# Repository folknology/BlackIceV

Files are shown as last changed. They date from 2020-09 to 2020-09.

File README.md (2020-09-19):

# BlackIce V
BlackIce V is the 6th generation of a long line of OpenSource Hardware FPGA boards designed by the myStorm community since 2016. Unlike it's predecessors based on the Ice40 HX range, the 'V' is based on the Lattice Ice40 UltraPlus up5K and offers great new features like DSP blocks and generous internal SRAM.

Current status is hardware design, you can see the developments we are making on my regular streams :
*  [Live Stream, 8pm BST](https://www.twitch.tv/folknology)
* [Historic streams](https://www.youtube.com/watch?v=79OoLG_Dxk0&list=PLXS9jyX9czzodpJNL-szsMfl0rOrZk4B7)
Or at the join us at the [myStorm community forum](https://forum.mystorm.uk)

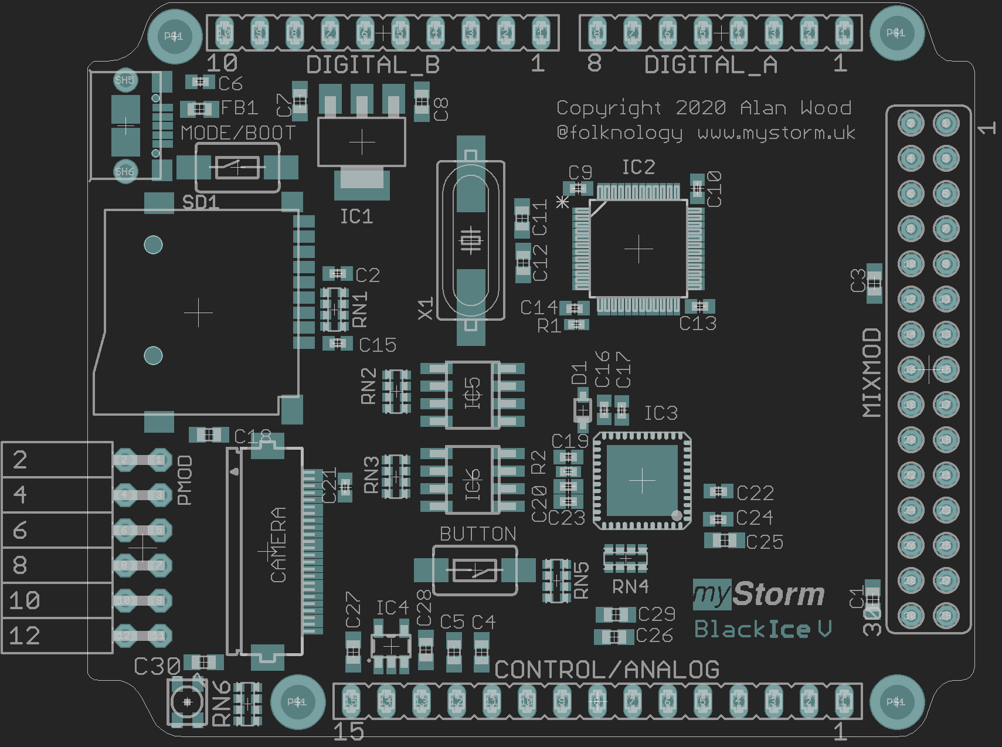
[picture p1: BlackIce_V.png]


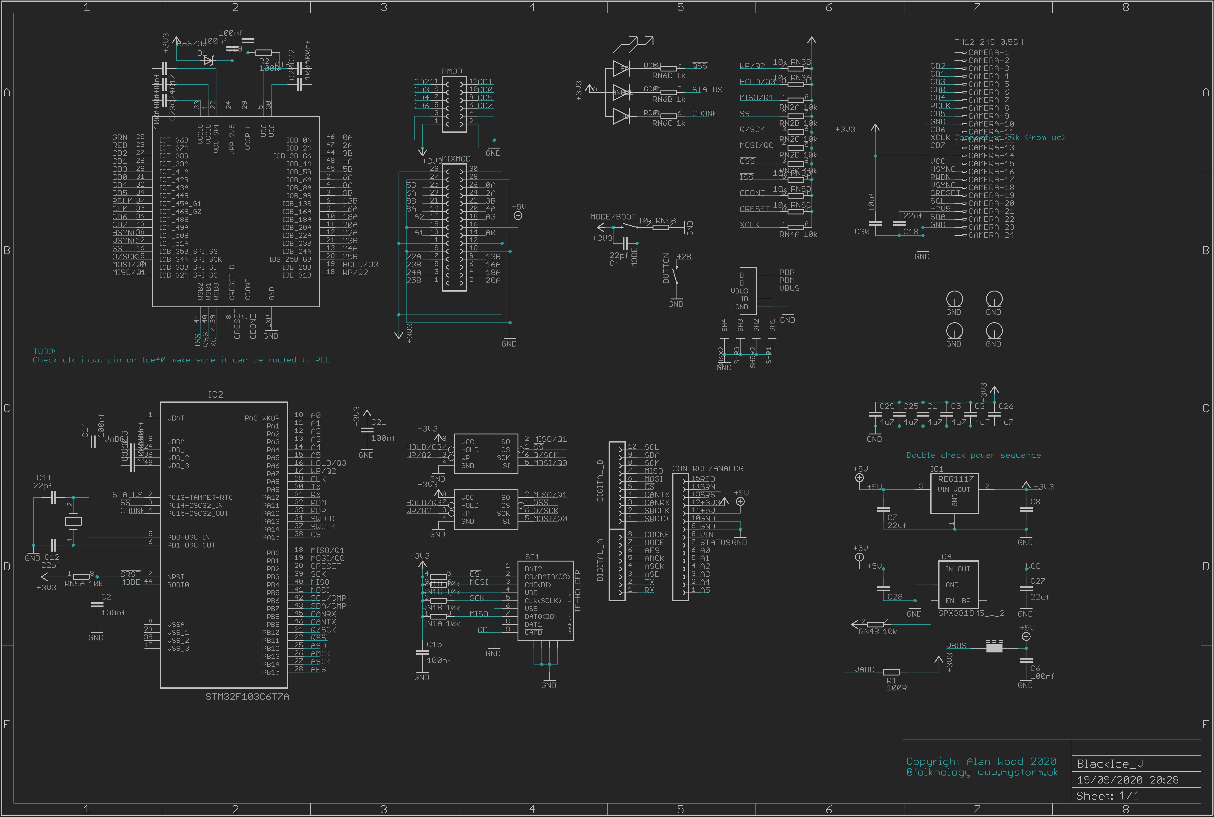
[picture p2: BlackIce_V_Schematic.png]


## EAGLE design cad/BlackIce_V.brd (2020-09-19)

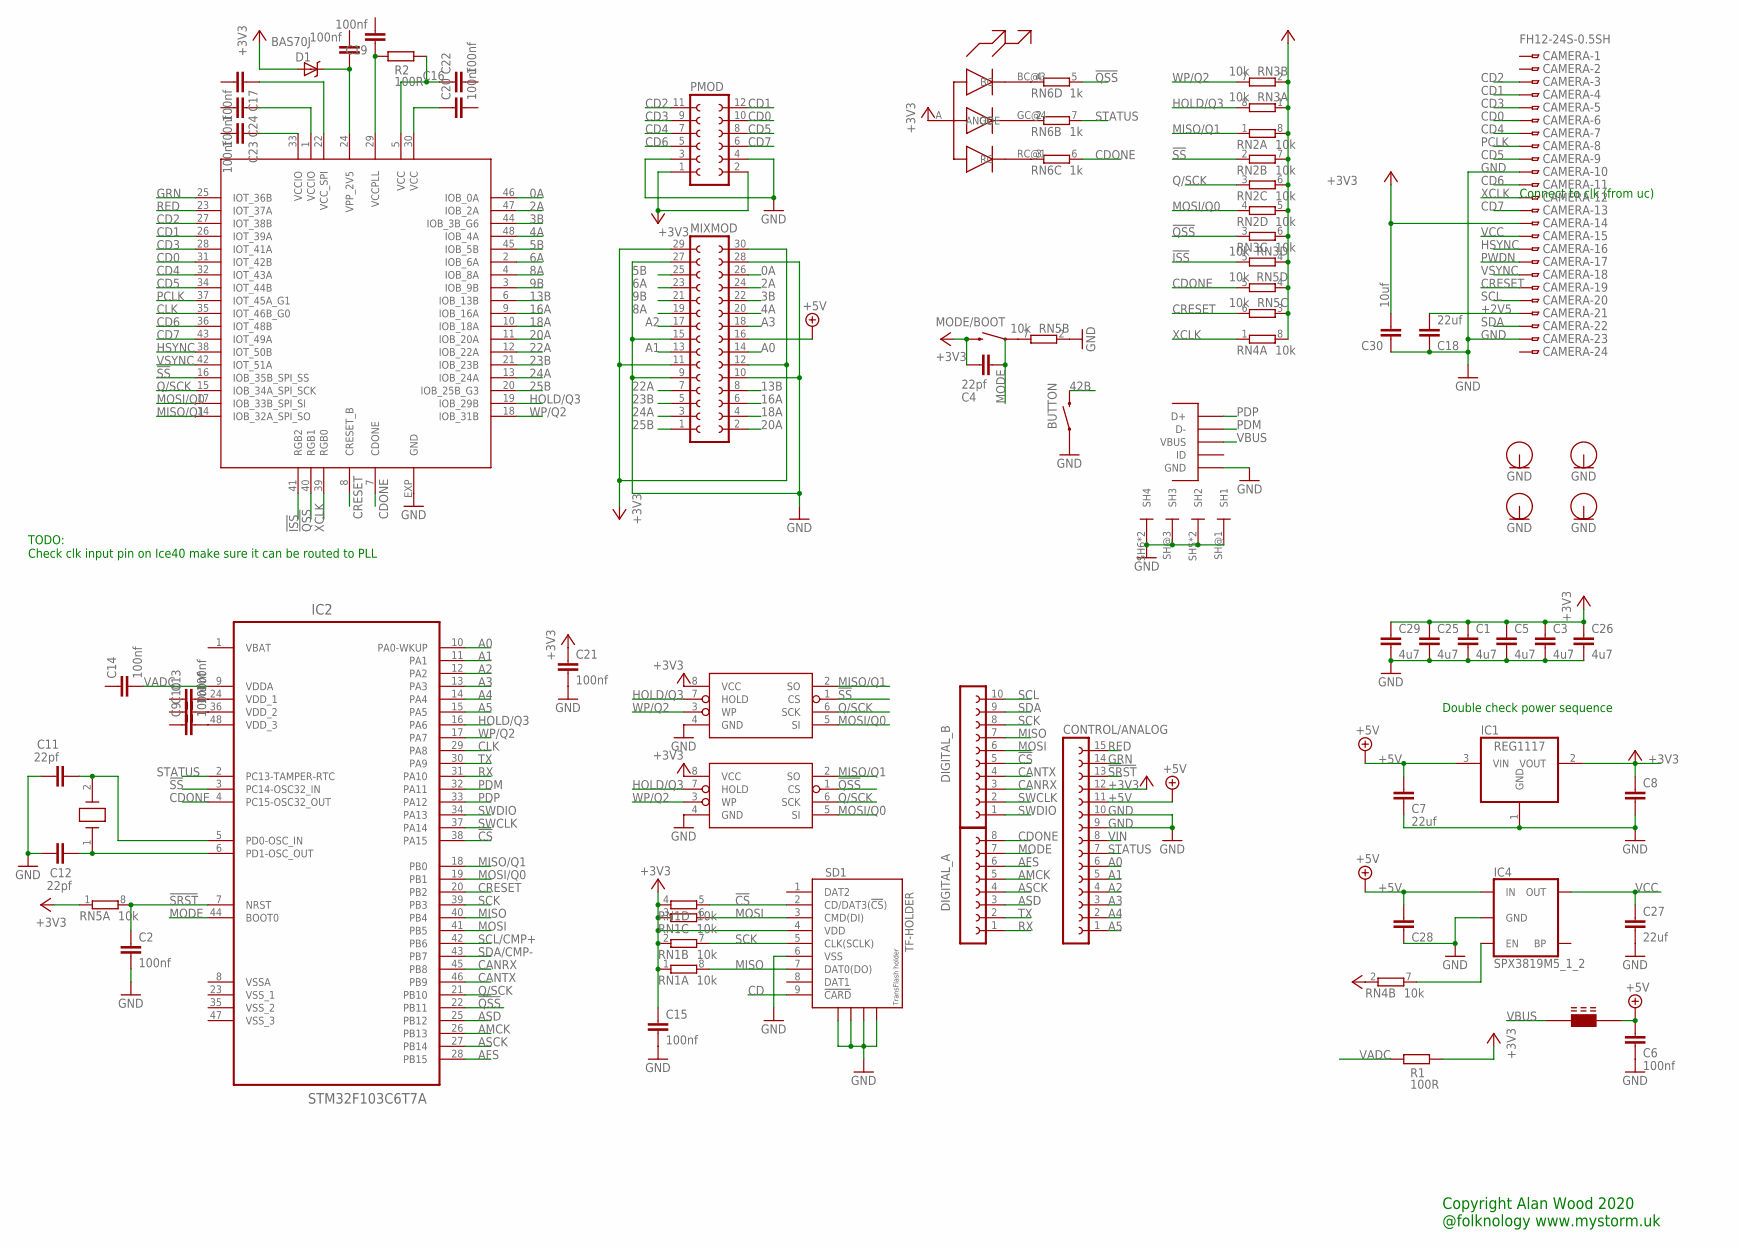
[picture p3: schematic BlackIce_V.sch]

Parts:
BUTTON: SWITCH-MOMENTARY-2SMD-1101NE; TACTILE-SWITCH-1101NE
C1, C3, C5, C25, C26, C29: 4u7; C0603
C2, C6, C9, C10, C13, C14, C15, C16, C17, C19, C20, C21, C22, C23, C24: 100nf; C0402
C4, C11, C12: 22pf; C0603
C7, C8, C18, C27, C28: 22uf; C0603
C30: 10uf; C0603
CAMERA: FH12-24S-0.5SH
CONTROL/ANALOG: FE15-1; FE15
D1: BAS70J; SOD-323
DIGITAL_A: FE08-1; FE08
DIGITAL_B: FE10-1; FE10
FB1: FERRITE_BEAD; 0603
H1, H2, H3, H4: HOLE2.5MM; 2.5MM-HOLE
IC1: REG1117; SOT223
IC2: STM32F103C6T7A; QFP50P900X900X160-48N
IC3: ICE40UP5K; QFN48
IC4: SPX3819M5_1_2; SOT23-5
IC5, IC6: AT25SDF041A; SOIC-8-NARROW
MIXMOD: FE15-2
MODE/BOOT: SWITCH-MOMENTARY-2SMD-1101NE; TACTILE-SWITCH-1101NE
PMOD: FE06-2W
R1, R2: 100R; R0402
RN1, RN2, RN3, RN4, RN5: 10k; 0603-ARV
RN6: 1k; 0603-ARV
SD1: TF-HOLDER; TF-PULL
U$1: FCI-MICROUSB-B-PEG; MICROUSB-B-PEG
U$4: RGB-PLCC-4; PLCC-4-SMALL
X1: HC49UP

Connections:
0A: IC3.46 (IOB_0A), MIXMOD.26
2A: IC3.47 (IOB_2A), MIXMOD.24
3B: IC3.44 (IOB_3B_G6), MIXMOD.22
4A: IC3.48 (IOB_4A), MIXMOD.20
5B: IC3.45 (IOB_5B), MIXMOD.25
6A: IC3.2 (IOB_6A), MIXMOD.23
8A: IC3.4 (IOB_8A), MIXMOD.19
9B: IC3.3 (IOB_9B), MIXMOD.21
13B: IC3.6 (IOB_13B), MIXMOD.8
16A: IC3.9 (IOB_16A), MIXMOD.6
18A: IC3.10 (IOB_18A), MIXMOD.4
20A: IC3.11 (IOB_20A), MIXMOD.2
22A: IC3.12 (IOB_22A), MIXMOD.7
23B: IC3.21 (IOB_23B), MIXMOD.5
24A: IC3.13 (IOB_24A), MIXMOD.3
25B: IC3.20 (IOB_25B_G3), MIXMOD.1
42B: BUTTON.2
!CS: DIGITAL_B.5, IC2.38 (PA15), RN1.5 (2), SD1.2 (CD/DAT3(!CS!))
!ISS: IC3.41 (RGB2), RN3.5 (2)
!QSS: IC2.22 (PB11), IC3.40 (RGB1), IC6.1 (CS), RN3.3 (1), RN6.5 (2)
!SRST: C2.1, CONTROL/ANALOG.13, IC2.7 (NRST), RN5.8 (2)
!SS: IC2.3 (PC14-OSC32_IN), IC3.16 (IOB_35B_SPI_SS), IC5.1 (CS), RN2.2 (1)
+2V5: C16.1, C18.1, CAMERA.21, D1.C, IC3.24 (VPP_2V5)
+3V3: C1.1, C3.1, C4.2, C5.1, C8.1, C15.1, C21.1, C25.1, C26.1, C29.1, C30.2, CAMERA.14, CONTROL/ANALOG.12, D1.A, IC1.2 (VOUT), IC5.8 (VCC), IC6.8 (VCC), MIXMOD.11, MIXMOD.12, MIXMOD.29, MIXMOD.30, MODE/BOOT.2, PMOD.1, PMOD.2, R1.1, RN1.1, RN1.2 (1), RN1.3 (1), RN1.4 (1), RN2.5 (2), RN2.6 (2), RN2.7 (2), RN2.8 (2), RN3.1, RN3.2 (1), RN3.4 (1), RN3.6 (2), RN4.2 (1), RN4.8 (2), RN5.1, RN5.3 (1), RN5.4 (1), SD1.4 (VDD), U$4.A (ANODE)
+5V: C6.2, C7.2, C28.2, CONTROL/ANALOG.11, FB1.2, IC1.3 (VIN), IC4.1 (IN), MIXMOD.16
A0: CONTROL/ANALOG.6, IC2.10 (PA0-WKUP), MIXMOD.14
A1: CONTROL/ANALOG.5, IC2.11 (PA1), MIXMOD.13
A2: CONTROL/ANALOG.4, IC2.12 (PA2), MIXMOD.17
A3: CONTROL/ANALOG.3, IC2.13 (PA3), MIXMOD.18
A4: CONTROL/ANALOG.2, IC2.14 (PA4)
A5: CONTROL/ANALOG.1, IC2.15 (PA5)
AFS: DIGITAL_A.6, IC2.28 (PB15)
AMCK: DIGITAL_A.5, IC2.26 (PB13)
ASCK: DIGITAL_A.4, IC2.27 (PB14)
ASD: DIGITAL_A.3, IC2.25 (PB12)
CANRX: DIGITAL_B.3, IC2.45 (PB8)
CANTX: DIGITAL_B.4, IC2.46 (PB9)
CD: SD1.9 (!CARD)
CD0: CAMERA.6, IC3.31 (IOT_42B), PMOD.10
CD1: CAMERA.4, IC3.26 (IOT_39A), PMOD.12
CD2: CAMERA.3, IC3.27 (IOT_38B), PMOD.11
CD3: CAMERA.5, IC3.28 (IOT_41A), PMOD.9
CD4: CAMERA.7, IC3.32 (IOT_43A), PMOD.7
CD5: CAMERA.9, IC3.34 (IOT_44B), PMOD.8
CD6: CAMERA.11, IC3.36 (IOT_48B), PMOD.5
CD7: CAMERA.13, IC3.43 (IOT_49A), PMOD.6
CDONE: DIGITAL_A.8, IC2.4 (PC15-OSC32_OUT), IC3.7 (CDONE), RN5.5 (2), RN6.6 (2)
CLK: IC2.29 (PA8), IC3.35 (IOT_46B_G0)
CRESET: CAMERA.19, IC2.20 (PB2), IC3.8 (CRESET_B), RN5.6 (2)
GND: BUTTON.1, C1.2, C2.2, C3.2, C5.2, C6.1, C7.1, C8.2, C11.1, C12.1, C15.2, C18.2, C21.2, C25.2, C26.2, C27.2, C28.1, C29.2, C30.1, CAMERA.10, CAMERA.23, CONTROL/ANALOG.9, CONTROL/ANALOG.10, H1.P$1, H2.P$1, H3.P$1, H4.P$1, IC1.1 (GND), IC3.EXP (GND), IC4.2 (GND), IC5.4 (GND), IC6.4 (GND), MIXMOD.9, MIXMOD.10, MIXMOD.15, MIXMOD.27, MIXMOD.28, PMOD.3, PMOD.4, RN5.2 (1), SD1.6 (VSS), SD1.S1, SD1.S2, SD1.S3, SD1.S4, U$1.P$5 (GND), U$1.SH5 (SH2), U$1.SH6 (SH4), U$1.SH@1 (SH1), U$1.SH@2 (SH2), U$1.SH@3 (SH3), U$1.SH@4 (SH4)
GRN: CONTROL/ANALOG.14, IC3.25 (IOT_36B)
HOLD/Q3: IC2.16 (PA6), IC3.19 (IOB_29B), IC5.7 (HOLD), IC6.7 (HOLD), RN3.8 (2)
HSYNC: CAMERA.16, IC3.38 (IOT_50B)
MISO: DIGITAL_B.7, IC2.40 (PB4), RN1.8 (2), SD1.7 (DAT0(DO))
MISO/Q1: IC2.18 (PB0), IC3.14 (IOB_32A_SPI_SO), IC5.2 (SO), IC6.2 (SO), RN2.1
MODE: C4.1, DIGITAL_A.7, IC2.44 (BOOT0)
MOSI: DIGITAL_B.6, IC2.41 (PB5), RN1.6 (2), SD1.3 (CMD(DI))
MOSI/Q0: IC2.19 (PB1), IC3.17 (IOB_33B_SPI_SI), IC5.5 (SI), IC6.5 (SI), RN2.4 (1)
unnamed: RN6.4 (1), U$4.BC@3 (BC)
unnamed: RN6.2 (1), U$4.GC@4 (GC)
unnamed: RN6.3 (1), U$4.RC@1 (RC)
unnamed: MODE/BOOT.1, RN5.7 (2)
unnamed: IC4.3 (EN), RN4.7 (2)
unnamed: C12.2, IC2.6 (PD1-OSC_OUT), X1.1 (X1)
unnamed: C11.2, IC2.5 (PD0-OSC_IN), X1.2 (X2)
unnamed: C13.2, IC2.24 (VDD_1)
unnamed: C10.2, IC2.36 (VDD_2)
unnamed: C9.2, IC2.48 (VDD_3)
unnamed: C23.1, IC3.33 (VCCIO)
unnamed: C24.1, IC3.1 (VCCIO)
unnamed: C17.1, IC3.22 (VCC_SPI)
unnamed: C19.1, IC3.29 (VCCPLL), R2.2
unnamed: C22.1, IC3.5 (VCC), R2.1
unnamed: C20.1, IC3.30 (VCC)
PCLK: CAMERA.8, IC3.37 (IOT_45A_G1)
PDM: IC2.32 (PA11), U$1.P$2 (D-)
PDP: IC2.33 (PA12), U$1.P$3 (D+)
PWDN: CAMERA.17
Q/SCK: IC2.21 (PB10), IC3.15 (IOB_34A_SPI_SCK), IC5.6 (SCK), IC6.6 (SCK), RN2.3 (1)
RED: CONTROL/ANALOG.15, IC3.23 (IOT_37A)
RX: DIGITAL_A.1, IC2.31 (PA10)
SCK: DIGITAL_B.8, IC2.39 (PB3), RN1.7 (2), SD1.5 (CLK(SCLK))
SCL: CAMERA.20, DIGITAL_B.10
SCL/CMP+: IC2.42 (PB6)
SDA: CAMERA.22, DIGITAL_B.9
SDA/CMP-: IC2.43 (PB7)
STATUS: CONTROL/ANALOG.7, IC2.2 (PC13-TAMPER-RTC)
SWCLK: DIGITAL_B.2, IC2.37 (PA14)
SWDIO: DIGITAL_B.1, IC2.34 (PA13)
TX: DIGITAL_A.2, IC2.30 (PA9)
VADC: C14.2, IC2.9 (VDDA), R1.2
VBAT: IC2.1 (VBAT)
VBUS: FB1.1, U$1.P$1 (VBUS)
VCC: C27.1, CAMERA.15, IC4.5 (OUT)
VIN: CONTROL/ANALOG.8
VSYNC: CAMERA.18, IC3.42 (IOT_51A)
WP/Q2: IC2.17 (PA7), IC3.18 (IOB_31B), IC5.3 (WP), IC6.3 (WP), RN3.7 (2)
XCLK: CAMERA.12, IC3.39 (RGB0), RN4.1

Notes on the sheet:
Double check power sequence
TODO: Check clk input pin on Ice40 make sure it can be routed to PLL
Connect to clk (from uc)
Copyright Alan Wood 2020 @folknology www.mystorm.uk

Board: 4 copper layers, 62 parts (0 on the bottom side), 91 nets, no tracks yet.

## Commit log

2020-09-19 Added the design and support files from local repo, community agreed name
    [BlackIce_V.brd, BlackIce_V.sch]
2020-09-19 Cleaned up the schematic a little and soretyed the Pmod signals (shared with Cam data)
    [BlackIce_V.brd, BlackIce_V.sch]

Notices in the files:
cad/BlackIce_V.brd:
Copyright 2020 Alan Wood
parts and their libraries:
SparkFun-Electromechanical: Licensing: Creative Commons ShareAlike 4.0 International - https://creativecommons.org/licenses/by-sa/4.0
